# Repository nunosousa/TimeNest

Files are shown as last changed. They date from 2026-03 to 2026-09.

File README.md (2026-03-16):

# TimeNest

<p align="center">
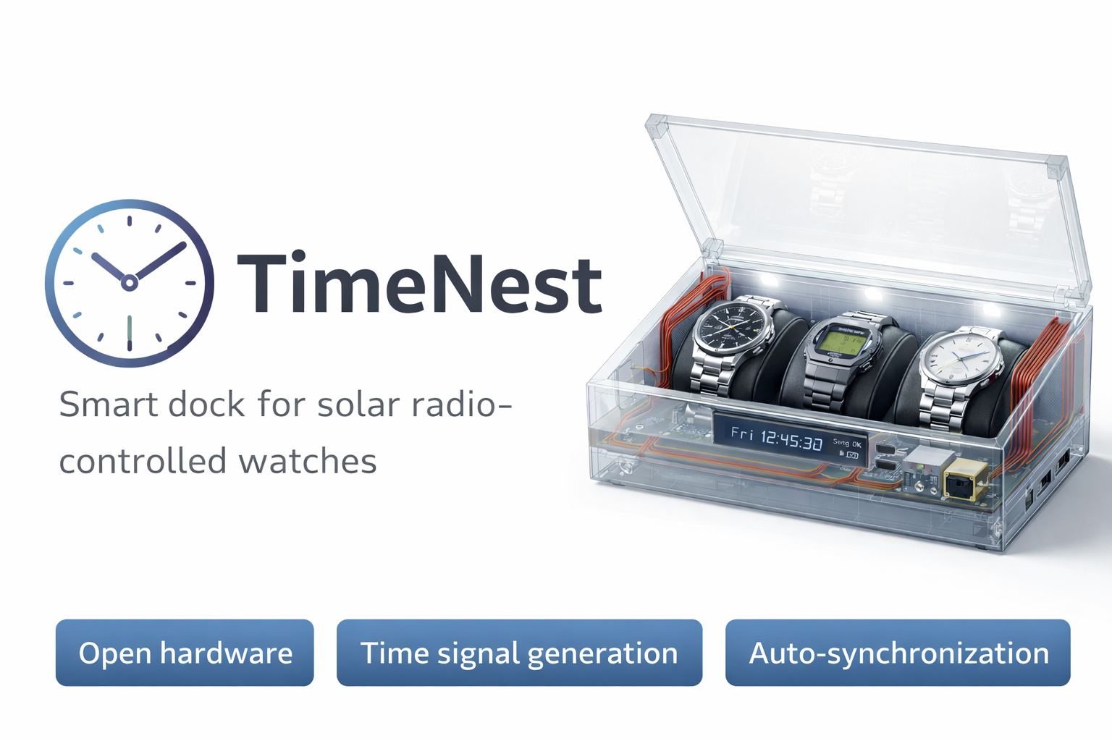
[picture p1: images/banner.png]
TimeNest banner
  
</p>

**TimeNest** is an open hardware dock that stores and automatically synchronizes radio-controlled solar watches using a locally generated low-frequency time signal.

The device acts as a **watch storage case, time synchronization beacon, and solar charging station**.

Watches placed inside the dock can synchronize reliably even in locations with poor LF radio reception.

---

## Overview

Many radio-controlled watches rely on long-wave radio signals (such as DCF77) to synchronize their time automatically.  
However, indoor reception can often be unreliable due to building structures and interference.

**TimeNest** solves this by generating a **local time signal** synchronized via the internet (SNTP) and transmitting it inside the watch case.

The result is a simple workflow:

1. Place watches inside the case  
2. Close the lid  
3. Watches synchronize automatically

---

## Features

### Radio Time Beacon

- Local generation of radio time signals (DCF77 initially)
- Near-field magnetic antenna
- Adjustable transmission power
- Designed to operate only within the watch case

### Watch Dock

- Storage for multiple watches
- Transparent lid
- Embedded antenna coils inside the case walls
- Elegant desk-friendly design

### Solar Charging

- LED illumination for solar watches
- Configurable brightness
- Optional ambient light sensing
- Illumination scheduling (e.g. daylight simulation)

### Connectivity

- Ethernet time synchronization (SNTP)
- Web configuration interface
- USB serial console for debugging and configuration

### Display

- Current time
- Synchronization status
- Transmission status
- System diagnostics

---

## System Architecture

- RP2040
    - Ethernet MAC + PHY (SPI)
    - lwIP + FreeRTOS
    - SNTP client
    - HTTP configuration server
    - USB serial console
    - DCF77 signal generator
    - external DAC
    - antenna driver
    - LED lighting control
    - display driver

## Platform Choice: RP2040

TimeNest is built around the **RP2040 microcontroller** rather than a microcontroller with an integrated Ethernet MAC. This decision was made deliberately based on several engineering and practical considerations.

### Availability and Supply Stability

One of the primary design goals for TimeNest is long-term reproducibility. During the global semiconductor shortages of 2020–2023 many commonly used MCUs became difficult to source, often with lead times exceeding a year.

The RP2040 demonstrated unusually strong supply stability during that period and remains widely available through multiple distributors. This makes it a reliable choice for a project intended to be reproducible by others in the future.

### Cost Efficiency

The RP2040 is inexpensive compared to many microcontrollers with integrated Ethernet peripherals. Even when combined with an external SPI Ethernet controller, the overall bill of materials remains competitive while retaining design flexibility.

### Strong Ecosystem

The RP2040 has a large and active ecosystem:

- extensive documentation
- a widely used SDK
- strong hobbyist and open hardware community
- support for multiple development environments

This lowers the barrier for contributors and improves long-term maintainability of the project.

### Deterministic Peripherals (PIO)

The RP2040 includes **Programmable I/O (PIO)** peripherals which allow precise timing control independent of the CPU.

This capability is particularly valuable for TimeNest because the device must generate a very stable **low-frequency radio time signal**. Using PIO allows deterministic waveform generation while the main CPU handles networking and other tasks.

### Dual-Core Architecture

The RP2040 provides two CPU cores, which allows the firmware to separate responsibilities:

- one core can handle networking, configuration, and user interface
- the other can manage the timing-critical signal generation tasks

This separation simplifies the firmware architecture and reduces the risk that networking activity interferes with signal timing.

### Flexible Networking Architecture

Although the RP2040 does not include an Ethernet MAC, TimeNest uses an external Ethernet controller connected via SPI.

This approach has several advantages:

- the networking stack remains fully software controlled
- updates and security fixes can be applied through the firmware
- the design avoids reliance on proprietary TCP/IP offload hardware

The project uses a standard embedded TCP/IP stack, making the networking layer maintainable and transparent.

### Simplicity and Accessibility

Another design goal for TimeNest is accessibility for hobbyists and hardware enthusiasts. The RP2040 is widely known and easy to work with, which makes the project easier to reproduce, understand, and modify.

---

### Summary

The RP2040 was chosen because it offers an excellent balance of:

- availability
- cost
- deterministic timing features
- strong community support
- long-term maintainability

While other microcontrollers could provide integrated Ethernet, the RP2040 provides the flexibility and ecosystem that best fit the goals of the TimeNest project.

---

## Why Generate a Local Radio Time Signal?

Many modern watches automatically synchronize their time using long-wave radio transmitters such as **DCF77 (Europe)**, **MSF (UK)**, **WWVB (USA)**, or **JJY (Japan)**.

However, reliable reception of these signals can be difficult indoors due to several factors:

- reinforced concrete buildings
- electrical interference
- distance from transmitters
- geographic coverage limitations

Even within nominal coverage areas, radio-controlled watches often fail to synchronize when placed inside buildings or urban environments.

TimeNest addresses this problem by generating a **local replica of the time signal** synchronized via the internet. The device obtains accurate time using SNTP and then reproduces the radio time signal within the enclosure.

This approach provides several advantages:

- reliable synchronization independent of outdoor reception
- consistent behavior regardless of building environment
- the ability to synchronize multiple watches simultaneously
- predictable synchronization during nightly update windows

By recreating the signal locally, TimeNest effectively acts as a **small personal time beacon** dedicated to the watches placed inside the dock.

---

## Near-Field Magnetic Transmission

TimeNest does not attempt to replicate a full long-range radio transmitter. Instead, it uses **near-field magnetic coupling** to deliver the time signal inside the watch enclosure.

Radio-controlled watches typically contain a **ferrite rod antenna** designed to detect the magnetic field component of long-wave signals. These antennas are very sensitive to nearby magnetic fields even when the radiated electric field is extremely small.

TimeNest takes advantage of this by generating a controlled magnetic field inside the watch case using tuned coils embedded in the enclosure walls.

This design has several benefits:

- extremely low transmission power
- minimal electromagnetic emissions outside the enclosure
- improved reliability for watches placed inside the case
- simplified antenna design

Because the signal only needs to be received within the watch compartment, the system operates entirely in the **near field** rather than attempting long-distance radio transmission.

The result is a compact and efficient system that reliably couples the time signal directly into the watch antennas while keeping the signal confined to the enclosure.

---

## Why Ethernet Instead of Wi-Fi?

TimeNest uses **wired Ethernet** as its network interface instead of Wi-Fi. This was a deliberate design choice based on simplicity, reliability, and the nature of the project.

### Simplicity of Implementation

The primary reason for choosing Ethernet is **system simplicity**.

Supporting Wi-Fi significantly increases firmware and system complexity. A Wi-Fi device must typically implement:

- network discovery and provisioning
- credential storage and management
- connection retry logic
- captive portal or mobile setup workflows
- security updates and maintenance

In contrast, Ethernet provides a **plug-and-play networking experience**:

1. Connect the cable.
2. Obtain an IP address via DHCP.
3. Start synchronizing time.

For a spare-time project, reducing firmware complexity greatly improves development speed and long-term maintainability.

### Reliability

Ethernet also offers **predictable and stable connectivity**. Wired networking avoids common Wi-Fi issues such as:

- RF interference
- signal dropouts
- congestion in the 2.4 GHz band
- router compatibility problems

For a device whose role is to **continuously obtain accurate time from the network**, a stable connection is desirable.

### Timing Considerations

TimeNest synchronizes time over the internet (e.g., via NTP) and generates a **DCF77-compatible time signal**. The required timing accuracy for this application is on the order of **tens of milliseconds**, which both Ethernet and Wi-Fi can easily support.

Therefore, Ethernet was **not chosen for better timing precision**—Wi-Fi would also be sufficient. The decision is instead driven by **simplicity and robustness**.

### Hardware and Firmware Complexity

Adding Wi-Fi would introduce additional hardware and software considerations:

- integration of a radio module
- antenna placement and RF layout constraints
- increased firmware stack complexity
- additional power consumption
- more complex debugging

Using Ethernet allows the device to remain **architecturally simple and deterministic**, which aligns well with the engineering goals of this project.

### Regulatory Considerations

Ethernet-only devices are treated as **unintentional radiators** from an electromagnetic compatibility (EMC) perspective. Adding Wi-Fi would turn the device into an **intentional RF transmitter**, bringing additional regulatory requirements under radio equipment directives.

While this is mainly relevant if the project were ever commercialized, avoiding an integrated radio simplifies the compliance landscape.

### Product Positioning

Many professional time distribution devices—such as **NTP servers and timing appliances**—use wired networking for the same reasons: reliability, determinism, and simplicity.

TimeNest follows this philosophy by favoring a **stable wired network interface** rather than a wireless one.

---

In short, Ethernet was selected because it provides the **simplest, most reliable, and most maintainable networking solution** for the goals of this project.

---

## Design Principles

TimeNest is designed as an open hardware project with an emphasis on simplicity, reproducibility, and responsible radio use. The following principles guide the design decisions throughout the project.

### Reproducibility

A core goal of TimeNest is that the device can be built and modified by others. Component choices and system architecture are selected with long-term availability in mind, and all design files are published in the repository.

The project includes:

- PCB design files
- firmware source code
- enclosure CAD models
- documentation describing design decisions

This allows others to reproduce, study, and extend the device.

### Modularity

TimeNest separates major system responsibilities into independent modules:

- RF signal generation
- networking and time synchronization
- user interface
- enclosure and antenna system

This modular structure simplifies development and makes the system easier to maintain or extend.

### Deterministic Timing

Generating a reliable radio time signal requires stable and predictable timing. The system architecture therefore prioritizes deterministic signal generation and isolates time-critical tasks from networking and user interface functionality.

This ensures that background tasks such as networking or configuration do not interfere with signal generation.

### Minimal RF Emissions

TimeNest is designed to operate entirely within the watch enclosure using near-field magnetic coupling rather than long-range radio transmission.

This approach:

- minimizes radiated emissions
- reduces interference with other devices
- keeps the system focused on synchronizing watches inside the dock

### Transparency

Design decisions are documented whenever possible so that the reasoning behind the system architecture is clear. Open documentation helps contributors understand the project and provides useful reference material for similar designs.

### Practical Simplicity

Where possible, the design favors simple and robust solutions over unnecessary complexity. The goal is a device that is reliable, understandable, and easy to reproduce rather than one that maximizes feature count.

---

## How It Works

TimeNest synchronizes radio-controlled watches by recreating a standard long-wave time signal inside the watch enclosure. The device obtains accurate time from the internet and converts it into a locally generated radio time signal that watches can receive.

The signal path can be summarized as follows:

<p align="center">
  
</p>

### Time Synchronization

TimeNest retrieves accurate time using **SNTP (Simple Network Time Protocol)** over Ethernet.  
The device periodically synchronizes with an NTP server and maintains a local system clock.

### Time Signal Encoding

Once the correct time is known, the firmware constructs the **DCF77 time frame**, which encodes:

- current minute
- hour
- date
- day of week
- daylight saving time information
- parity bits

DCF77 transmits one bit per second using amplitude modulation of a 77.5 kHz carrier.

### Carrier Generation

The RF carrier is generated using a **Direct Digital Synthesis (DDS)** approach implemented on the RP2040.  
The DDS produces a stable 77.5 kHz waveform that serves as the carrier for the time signal.

### Modulation

The DCF77 signal encodes bits using brief reductions in carrier amplitude:

- **100 ms reduction** → logical 0  
- **200 ms reduction** → logical 1  

The firmware controls this modulation pattern according to the generated time frame.

### Analog Signal Output

The synthesized waveform is converted to an analog signal using a **digital-to-analog converter (DAC)** and then amplified by a small RF driver stage.

### Magnetic Field Generation

The amplified signal drives **resonant antenna coils embedded in the enclosure walls**. These coils generate a low-frequency magnetic field inside the watch compartment.

Because radio-controlled watches use **ferrite rod antennas**, they can detect this magnetic field even though the transmission power is extremely small.

### Watch Synchronization

Watches placed inside the dock receive the locally generated signal just as they would receive the original DCF77 transmission. During their normal nightly synchronization window, the watches decode the signal and update their internal clocks.

By generating the signal locally, TimeNest ensures reliable synchronization even in environments where the original long-wave broadcast cannot be received.

---

## Hardware

Main components include:

- RP2040 microcontroller
- SPI Ethernet controller
- external DAC for signal generation
- resonant LF antenna coils
- LED lighting system
- small display
- optional RTC

Hardware design files can be found in:

hardware/pcb

---

## Antenna

TimeNest uses **near-field magnetic transmission**.

Two coils embedded in the case walls generate a uniform magnetic field inside the watch compartment, allowing reliable synchronization for all watches inside the box.

---

## Enclosure

The enclosure is a **3D-printed watch case** designed to hold multiple watches.

Features include:

- transparent lid
- integrated antenna coils
- solar charging LEDs
- front status display
- rear connectors (Ethernet, USB, power)

CAD files are located in:

enclosure/cad

---

## Repository Structure

- TimeNest
    - firmware/ RP2040 firmware
    - hardware/ schematics and PCB layout
    - enclosure/ CAD models and STL files
    - docs/ design notes and documentation
    - images/ renders and photos

---

## Roadmap

| Feature | Status |
|---|---|
| Project concept | ✅ done |
| System architecture | 🔄 in progress |
| RP2040 platform selection | 🔄 in progress |
| DCF77 signal generator | ⏳ planned |
| DAC output stage | ⏳ planned |
| Antenna design | ⏳ planned |
| Ethernet networking | ⏳ planned |
| SNTP time synchronization | ⏳ planned |
| Web configuration interface | ⏳ planned |
| USB debug interface | ⏳ planned |
| Solar charging LEDs | ⏳ planned |
| Enclosure CAD design | ⏳ planned |
| Multi-protocol support (WWVB / MSF / JJY) | 💡 future idea |

Legend:

⏳ planned

🔄 in progress

✅ done

💡 future idea

---

## Development Log

- 2026-03 — project started
- architecture defined
- antenna concept explored
- enclosure concept designed

More updates will be added as development progresses.

---

## Getting Started

Documentation and assembly instructions will be added as the hardware and firmware mature.

---

## Contributing

Contributions, ideas, and feedback are welcome.

If you are interested in:

- RF design
- embedded firmware
- mechanical design
- watch technology

feel free to open an issue or start a discussion.

---

## Project Status

TimeNest is currently in **early development**.

## Acknowledgements

Some parts of the project documentation and early concept brainstorming were assisted by AI tools.  
All hardware, firmware, and mechanical design decisions are reviewed and implemented by the project author.

## License

TimeNest is an open hardware project.

Different parts of the project are licensed under different licenses:

| Component | License |
|---|---|
Firmware | MIT License |
Hardware (schematics, PCB) | CERN-OHL-S v2 |
Enclosure CAD | CERN-OHL-S v2 |
Documentation and images | CC BY 4.0 |

See the `LICENSES` folder for full license texts.

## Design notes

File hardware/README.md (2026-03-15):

# Hardware

This directory contains the electronic design files for TimeNest.

## Contents

- schematics
- PCB layout
- component libraries
- manufacturing files

The main PCB includes:

- RP2040 microcontroller
- Ethernet MAC/PHY
- DAC for signal generation
- antenna driver
- LED drivers
- power supply circuitry

## Tools

The PCB is designed using KiCad.

## Status

Hardware design is currently in early development.

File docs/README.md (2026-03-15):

# Documentation

This directory contains technical documentation related to the TimeNest project.

Topics include:

- antenna design
- RF signal generation
- system architecture
- testing procedures
- assembly instructions

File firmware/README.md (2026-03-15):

# Firmware

This directory contains the firmware for the TimeNest device.

The firmware runs on the RP2040 microcontroller and is responsible for:

- generating the DCF77 signal
- controlling the antenna driver
- managing LED solar charging
- providing USB console access
- handling Ethernet networking and SNTP synchronization
- driving the display

## Structure

rp2040/ main firmware project

drivers/ hardware drivers

protocols/ time signal generation

ui/ display and console interface

## Build System

Firmware is built using the RP2040 SDK.

Further build instructions will be added as development progresses.

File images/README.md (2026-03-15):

# Images

This directory contains project images used in documentation.

Examples:

- device renders
- architecture diagrams
- PCB previews
- antenna illustrations

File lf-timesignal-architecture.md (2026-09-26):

# LF Time-Signal Generator — Architecture Sketch
## (single-standard per build, five variants from one design)

Target: a near-field transmitter that emits **one** LF time signal — DCF77,
WWVB, MSF, JJY (40/60) or BPC — to synchronise consumer radio-controlled
watches and clocks, with full fidelity including DCF77 phase modulation and
WWVB BPSK.

**The standard is fixed at build time**, not runtime-selectable: one PCB design
with a per-variant BOM (tank capacitor, PLL constants) and firmware build flag.
This constraint is exploited throughout — in §2, §3 and §6 it removes problems
rather than adding them.

**Companion documents:**
- `lf-timesignal-requirements.md` — formal design requirements
- `lf-timesignal-hardware.md` — schematic blocks, part selection, PCB design

---

## 1. Top-level block diagram

```
 ┌────────────┐  UART+PPS   ┌──────────────────────────────────────┐
 │ GNSS module├────────────►│              RP2350                  │
 └────────────┘             │                                      │
 ┌────────────┐    I2C      │  core0: timebase, GNSS, UI, config    │
 │ RTC+cell   ├────────────►│  core1: NCO sample synthesis          │
 └────────────┘             │  PIO0:  R-2R sample clock (DMA fed)   │
 ┌────────────┐             │  PIO1:  PPS capture / spare           │
 │ TCXO       ├──► XIN      └───────────────┬──────────────────────┘
 └────────────┘                             │ 10-bit parallel
                                            ▼
                              ┌──────────────────────────┐
                              │ R-2R ladder (10-bit)     │
                              └────────────┬─────────────┘
                                           ▼
                              ┌──────────────────────────┐
                              │ Reconstruction LPF ~120k │
                              └────────────┬─────────────┘
                                           ▼
                              ┌──────────────────────────┐
                              │ Linear driver (op-amp)   │
                              └────────────┬─────────────┘
                                           ▼
                              ┌──────────────────────────┐
                              │ Untuned / damped loop    │
                              └──────────────────────────┘
```

Everything downstream of the R-2R is **linear** — no switching stages — because
the signal now carries simultaneous amplitude *and* phase information.

---

## 2. Clocking and the sample rate — **coherent sampling, per variant**

Because each unit is built for **one** standard (see §2a), the system clock and
sample rate are chosen per variant so that:

```
Fs = N × f_carrier     (N = integer samples per carrier cycle)
sysclk = M × Fs        (M = integer PIO divider)
Fs = integer samples per second
```

This is *coherent sampling*, and it is only possible in a single-standard build.
It is a large simplification — see §3 for why.

| Variant | sysclk | PLL (refdiv/fbdiv/VCO/p1/p2) | Fs | N (samp/cycle) | PIO div | cycles/sample |
|---|---|---|---|---|---|---|
| DCF77 77.5k | 116.25 MHz | 2 / 155 / 930 MHz / 2 / 4 | 1.550 MS/s | 20 | 75 | 75 |
| WWVB 60k | 102.00 MHz | 1 / 68 / 816 MHz / 2 / 4 | 1.200 MS/s | 20 | 85 | 85 |
| MSF 60k | 102.00 MHz | 1 / 68 / 816 MHz / 2 / 4 | 1.200 MS/s | 20 | 85 | 85 |
| JJY 40k | 100.00 MHz | 1 / 75 / 900 MHz / 3 / 3 | 0.800 MS/s | 20 | 125 | 125 |
| BPC 68.5k | 102.75 MHz | 2 / 137 / 822 MHz / 2 / 4 | 1.370 MS/s | 20 | 75 | 75 |

All verified against RP2350 PLL constraints (VCO 750–1600 MHz, fbdiv 16–320,
postdiv 1–7). **N = 20 for every variant**, so the sine LUT, the DDS inner loop
and the DMA block sizing are identical across the whole family — only three
constants change.

Note that **BPC's awkward prime 137 is no longer a problem**: it is absorbed
directly into the PLL feedback divider (refdiv 2, fbdiv 137 → 822 MHz VCO). The
factor that made a runtime-switchable design impossible is free in a
per-variant one.

Sysclk also drops from 150 MHz to ~100–116 MHz, which reduces power and
lengthens the per-sample CPU budget.

---

## 2a. Product variants

One PCB, one firmware tree, per-variant BOM and build flags. Two complexity
tiers fall out of *which standards carry phase modulation*:

| Tier | Standards | Modulation | Signal chain |
|---|---|---|---|
| **Full** | DCF77, WWVB | AM **+ phase** (PRBS / BPSK) | NCO → R-2R → LPF → linear driver |
| **Simple** | MSF, JJY, BPC | AM / OOK only | PIO square wave → keying → tank |

The Simple tier needs no DAC, no linear amplifier and no reconstruction filter —
a PIO square wave into a tuned tank with switched drive is sufficient, because
there is no phase information to preserve. That is a materially cheaper kit.

**Recommendation: lay out one PCB that supports both**, with the R-2R ladder,
filter and linear driver as do-not-populate options on Simple-tier builds. Two
separate PCB designs would double layout, inventory and test-fixture work to
save a few euro of parts.

Per-variant differences are then: crystal/PLL constants, tank capacitor,
firmware build flag, silkscreen, and test limits.

---

## 3. The NCO — now *coherent*, which removes two problems

With Fs locked to an integer multiple of the carrier (N = 20), the NCO stops
being a general-purpose DDS and becomes something much simpler and more exact.

**The phase accumulator no longer accumulates error.** With N = 20 samples per
cycle, the carrier phase advances by exactly 1/20 turn per sample. A 20-entry
sine table *is* the carrier. There is no phase truncation, no fractional
residual, and therefore **no DDS phase-truncation spurs** — which were the main
spectral risk of the original design.

Keep a 32-bit accumulator anyway (it costs nothing and preserves the ability to
trim frequency for calibration), but the steady-state increment is now the exact
value `2^32 / 20`, and the arithmetic closes perfectly every 20 samples.

Modulation is unchanged and still trivial:
- **PM/BPSK** = add to `phase_offset` (±15.6° DCF77, 180° WWVB)
- **AM** = scale `amplitude` (15% DCF77, −17 dB ≈ 14.1% WWVB, 0% MSF, ~10% JJY)

Because a full carrier cycle is exactly 20 samples, a 180° BPSK reversal is
exactly a 10-sample index offset, and DCF77's ±15.6° needs interpolation or a
slightly larger LUT (a 256-entry table indexed by the accumulator's high bits
handles both cleanly).

### The DCF77 chip-alignment problem disappears

Previously flagged as a trap: at 2 MS/s a DCF77 PM chip was 3096.774 samples —
not an integer — so a sample counter would drift against the chip clock.

With coherent sampling this vanishes:

```
chip = 120 carrier cycles × 20 samples/cycle = 2400 samples, exactly
```

No overflow-counting workaround, no drift, no self-aligning trickery. A plain
sample counter is now exact. Similarly one second = 1 550 000 samples exactly,
so second boundaries and chip boundaries stay locked forever.

This is the single strongest argument for the per-variant approach.

### DCF77 PM timing, in samples (verified self-consistent)

| Event | Time | Samples @ 1.55 MS/s |
|---|---|---|
| 1 carrier cycle | 12.9 µs | 20 |
| 1 second | 1 s | 1 550 000 |
| 1 PM chip (120 cycles) | 1.5484 ms | 2 400 |
| PM start | +200 ms | 310 000 |
| PM duration (512 chips) | 792.77 ms | 1 228 800 |
| PM end | +992.77 ms | 1 538 800 |
| Guard before next second | 7.23 ms | 11 200 |
| AM drop, bit 0 | 100 ms | 155 000 |
| AM drop, bit 1 | 200 ms | 310 000 |
| AM ramp | 1.0 ms | 1 550 |

512 chips at 645.833 Hz = 792.77 ms, starting at +200 ms, ending at +992.77 ms —
inside the second with 7.23 ms to spare. The +200 ms start is exactly what keeps
PM clear of the longest AM drop, satisfying the "no phase modulation during the
amplitude drop" constraint structurally rather than by special-casing.

Every quantity above is an exact integer number of samples.

---

## 3a. Epoch discipline without touching the carrier

A subtle but important consequence of coherent sampling.

The carrier NCO **free-runs and is never steered**. Because f_c = F_s/20 is
structural, a reference-oscillator error scales the carrier, the chip rate and
the second length *together* — so a DCF77 chip stays exactly 120 carrier cycles
no matter how far off the crystal is.

Timing is therefore disciplined in the **event scheduler**, not the oscillator:
maintain a fractional samples-per-second accumulator (nominally 1 550 000) and
steer it against GNSS PPS. Because the carrier accumulator is untouched, this
introduces **no carrier phase glitch** — which would otherwise corrupt PM and
BPSK, and would be very hard to diagnose.

Consequences:
- Carrier accuracy requirement is loose (±10 ppm), so the reference is chosen
  for **holdover stability**, not absolute accuracy.
- Steering resolution is unlimited (fixed-point remainder), not quantised to
  whole samples.
- Never implement discipline by inserting/dropping samples: at 20 samples per
  cycle, one sample is an 18° phase step.

---

## 4. Software layering

Three layers with narrow interfaces. The whole point is that adding a sixth
standard should touch only layer 2.

### Layer 1 — Timebase service
Produces a sample-accurate UTC: `(utc_seconds, sample_within_second)`.

- GNSS PPS captured against the free-running sample counter.
- Steer/align the second boundary; measure TCXO error over long intervals and
  store the learned ppm correction in flash for holdover.
- Leap-second state (current + pending) taken from the GNSS navigation message.
- RTC (battery-backed) provides time across power cycles.

### Layer 2 — Standard / protocol layer
`utc → local time for that standard → frame bits → symbol schedule`

- DST/offset rule engine (§5).
- One frame encoder per standard, each a pure function of civil time → bits.
- Emits a **symbol schedule**: a list of
  `{ sample_offset, amplitude_q15, phase_offset_q32, ramp_samples }` events for
  the coming second, plus an optional PRBS generator hook for DCF77 PM.

### Layer 3 — Modulator
Consumes the symbol schedule, runs the NCO, fills double-buffered DMA blocks
(e.g. 512 samples) on core1. Knows nothing about time or standards.

This split keeps the twice-a-year DST bugs and the real-time DSP in completely
separate, separately-testable code.

---

## 5. Time, date and DST — no network needed

GNSS supplies UTC, date and leap-second data (including *pending* leap seconds,
which is better than NTP's last-day-only leap indicator).

**Holdover is the binding constraint, not acquisition.** Measured budget:

| Reference | Residual | Drift | Reaches 100 ms in |
|---|---|---|---|
| Plain XTAL, uncorrected | 30 ppm | 2.6 s/day | 1 hour |
| Plain XTAL, ppm learned | ~3 ppm | 259 ms/day | 9 hours |
| TCXO 2 ppm | 2 ppm | 173 ms/day | 14 hours |
| **TCXO 0.5 ppm** | 0.5 ppm | 43 ms/day | **2.3 days** |

Even a good TCXO holds ±100 ms for only about two days, so **"get one fix at
setup and run forever" is not viable**. The design answer is duty-cycled GNSS:
re-acquire hourly (cheap in power, ~seconds of tracking), and treat true
holdover as a degraded mode specified at ±500 ms over 7 days — which 0.5 ppm
does meet.

This also means the GNSS antenna should be external and user-placeable, not a
patch buried in the enclosure.

GNSS does not supply timezone or DST rules — but none of these standards need a
tzdata database, because each broadcasts exactly one zone under one fixed
algorithmic rule:

| Standard | Zone | DST rule |
|---|---|---|
| DCF77 | CET/CEST | EU: last Sun Mar 01:00 UTC → summer; last Sun Oct 01:00 UTC → winter |
| MSF | UTC/BST | Same instants as the EU rule |
| WWVB | UTC + DST status bits | US: 2nd Sun Mar, 1st Sun Nov |
| JJY | JST (UTC+9) | None |
| BPC | UTC+8 | None |

~30 lines of "Nth/last Sunday of month" arithmetic. **Store the rule parameters
in flash, not hardcoded**, so a future EU decision to abolish DST is a config
change rather than a firmware respin.

Announce bits are computed from the same rules: DCF77 A1 (bit 16) during the
hour before a change, A2 (bit 19) for leap seconds, and WWVB's DST status bits.
*Pin the exact announce timing against the PTB and NIST specs — these are the
classic "works all year, fails twice a year" defects.*

---

## 6. Output stage — now tuned, but *not* high-Q

Per-variant tuning removes the objections that forced an untuned loop in the
runtime-switchable design: a single fixed resonant frequency means **no switched
capacitor bank and no per-band phase calibration**. So yes — resonate.

The question becomes *how high a Q*, and there are two independent ceilings.

### Ceiling 1 — modulation bandwidth

`BW = f0 / Q`, ring-down `τ = Q / (π·f0)`.

| Variant | Constraint | Required BW | Q ceiling |
|---|---|---|---|
| DCF77 | PM chips at 645.83 Hz | ≳ 3 kHz | **~25** |
| WWVB | BPSK reversal, 1 baud | transient ≪ 1 s | ~100 |
| MSF | OOK, 100 ms off | ring-down ≪ 100 ms | ~100 |
| JJY / BPC | AM, ≥ 200 ms | loose | ~100 |

Only DCF77 is genuinely tight. At Q = 25 its ring-down is 103 µs — negligible
against a 100 ms AM step, while still passing the phase chips.

### Ceiling 2 — manufacturability (this is the binding one for a kit)

At Q = 50 and 77.5 kHz the passband is 1550 Hz. A ±5% capacitor shifts
resonance by ~2.5%, i.e. ~1900 Hz — **further than the bandwidth is wide**. The
unit would ship detuned off its own peak.

High Q therefore forces either 1% C0G capacitors *and* a per-unit tuning step,
or a trimmer the customer must adjust with test gear they don't own. For a kit,
that is a support disaster.

**Q ≈ 20–25 is the sweet spot, and it is the same answer for every variant.**
It satisfies DCF77's phase modulation, tolerates ±2–3% component spread with no
per-unit tuning, and keeps one Q target across the whole product family.

Use **C0G/NP0 capacitors** regardless — X7R's temperature and DC-bias drift
would detune the tank across the operating range.

### Don't over-value the range gain

Field strength in a series-resonant loop scales with Q, but near-field coupling
falls as 1/r³. So going Q = 25 → 100 (4× current) buys only ∛4 ≈ **1.6× range**.
Paying for per-unit tuning to gain 60% more distance on a device meant to work
at a few centimetres is a bad trade.

### Worked example (DCF77)

L = 1 mH at 77.5 kHz → ωL = 487 Ω. C = 4.22 nF (C0G).
For Q = 25, total series R = 19.5 Ω. Ring-down τ = 103 µs. BW = 3.1 kHz.

### Drive requirement — no power amplifier needed

Computed field strength settles this. A 100-turn, 5 cm-radius loop at **10 mA
peak** sits roughly **65 dB under FCC §15.209** and **70 dB under EN-300-330**-
style limits, while still delivering a very strong near-field at watch distance.

| Coil current | Drive voltage | Power | Voltage across L |
|---|---|---|---|
| 10 mA pk | 0.19 V pk | 1.0 mW | 4.9 V pk |
| 30 mA pk | 0.58 V pk | 8.8 mW | 14.6 V pk |
| 50 mA pk | 0.97 V pk | 24.3 mW | 24.3 V pk |

The "linear amplifier" in the original block diagram is therefore just an
op-amp: 1 mW, 0.19 V peak, and a slew-rate requirement of 0.49 V/µs. Select for
distortion, not for power.

⚠️ **The voltage across the inductor is Q× the drive** — 24 V peak at 50 mA on a
5 V system. Rate the tank capacitor ≥50 V. This is the standard resonant-circuit
trap and the one place in this design where a 5 V assumption will destroy parts.

### DAC and filter (Full tier only)

10-bit R-2R, PIO+DMA driven, 0.1% resistors (1% parts give ~7 effective bits;
WWVB's −17 dB level wants ~1% amplitude accuracy). Reconstruction LPF at
~120 kHz. Phase resolution lives in the NCO, not the DAC — DAC bits bound only
amplitude accuracy and the spurious floor.

Simple-tier variants (MSF/JJY/BPC) omit all of this: PIO square wave → keyed
drive → tank. The tank's own selectivity suppresses the square wave's harmonics.

---

## 7. Pin budget (RP2350)

| Function | Pins |
|---|---|
| R-2R ladder | 10 |
| GNSS UART (TX/RX) | 2 |
| GNSS PPS | 1 |
| GNSS enable | 1 |
| I2C (RTC + OLED) | 2 |
| Amplifier mute/enable | 1 |
| UI (encoder + button) | 3 |
| Status LED | 1 |
| Optional band-select switches | 3 |
| **Total** | **~21–24** |

Fits the 30-GPIO QFN-60 package with margin. Simple-tier variants free the 10
R-2R pins, leaving room for a cheaper/smaller package if a cost-reduced SKU is
ever wanted.

---

## 8. Configuration and UX

The standard is **fixed at build time** (BOM + firmware flag), so there is no
runtime standard selector. What remains configurable in flash:

- TX power trim, DST rule parameters, learned TCXO ppm, transmit window.
- No OLED/encoder needed for standard selection — a status LED plus USB-C serial
  config is sufficient, which cuts BOM and enclosure cost.
- **Transmit window scheduler**: most radio-controlled watches only attempt sync
  overnight (typically 02:00–04:00), so the device can idle most of the day.
  Cuts duty cycle, power and regulatory exposure — and is a genuine product
  feature ("only radiates 20 minutes a night").
- Provide a manual "sync now" button for watches that support forced receive;
  without it, development iterations take hours.
- **Have the firmware refuse to run if the build flag and a hardware strap
  disagree.** A DCF77 board flashed with WWVB firmware would transmit off-tune
  into a Q=25 tank and mostly just not work — an expensive support ticket.
  A single resistor strap per variant makes this self-detecting.

---

## 9. Test and validation strategy

- **A 192 kHz USB audio interface is your best analysis tool.** Nyquist is
  96 kHz, so all five carriers (40, 60, 68.5, 77.5 kHz) fit directly in the
  audio band. No SDR or upconverter needed — capture the loop with a pickup coil
  and decode/analyse in software.
- Commercial DCF77/WWVB/MSF receiver modules as golden-reference decoders.
- A second RP2350 running a decoder for loopback regression tests.
- **Golden-vector unit tests**: known timestamp → expected bit pattern, per
  standard, checked bit-for-bit against published examples.
- **Sweep the DST engine across ~20 years** of transitions in unit tests,
  including the leap-second and announce-bit edges.
- **Per-variant production test**: sweep the tank and confirm resonance lands
  within ±1% of target. Cheap to automate with the same audio interface, and it
  is the one build defect (wrong/out-of-tolerance capacitor) most likely to
  escape a kit builder.

---

## 10. Risks

| Risk | Severity | Mitigation |
|---|---|---|
| Regulatory compliance **per variant per region** | **High** | Each variant is a separate frequency in a separate jurisdiction — FCC (WWVB), CE/UKCA (DCF77/MSF), MIC (JJY, notoriously strict). Cost multiplies per variant, so launch **one** variant first and treat others as gated business decisions, not engineering tasks |
| GNSS never gets a fix indoors | High | RTC holdover + learned TCXO correction; only needs one fix at setup; USB time-set fallback |
| Kit builder mis-tunes or mis-stuffs the tank | Medium | Q≈25 tolerates ±2–3% spread; ship pre-matched L/C pair; hardware strap + firmware self-check |
| DCF77 PRBS spec details (sequence, start offset within the second) | Medium | Obtain PTB specification before committing to layer-2 design |
| WWVB BPSK +0.1 s offset implemented wrong | Medium | Breaks BPSK receivers while AM ones still work — looks intermittent. Cover with golden vectors |
| R-2R amplitude accuracy (Full tier only) | Low | 0.1% resistors, or monolithic DAC in production |
| GPS week rollover | Low | Current module firmware; handle epoch explicitly |
| BPC spec availability (Chinese-language sources) | Low | Defer to last; lowest commercial value |

Note that selling a **kit** rather than a finished product does not reliably
reduce regulatory obligation — do not assume it does without advice.

---

## 11. Phased roadmap

Build **one variant end-to-end** before generalising. DCF77 first: it is your
own use case and it is the hardest (phase modulation + tightest Q ceiling), so
it validates every constraint the other variants will face.

| Phase | Goal | Proves |
|---|---|---|
| P0 | DCF77 AM only, square wave into a coil, time hardcoded | A watch actually syncs — de-risks the whole product in a weekend |
| P1 | NCO + R-2R + LPF + linear driver + Q≈25 tank, DCF77 AM | Coherent-sampling signal chain and CPU budget |
| P2 | DCF77 phase modulation | Hardest DSP; validates the Q≈25 ceiling |
| P3 | GNSS + PPS discipline + RTC holdover + DST engine | Standalone operation — **first sellable product** |
| P4 | Second variant (WWVB or MSF) | Layer-2 abstraction and the per-variant BOM actually hold |
| P5 | Enclosure, config, per-region compliance | Sellable abroad |
| P6 | JJY, BPC | Completeness |

Compared with the runtime-switchable plan, GNSS/DST moves **earlier** (it is
needed for a shippable single-standard unit) and multi-standard work moves
**later** (it is now a business decision gated on compliance cost, not a
prerequisite).

Do P0 first and separately. It is a few hours of work and it answers the only
question that really matters: do your watches sync to a locally generated
signal at all?

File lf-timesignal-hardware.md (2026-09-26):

# LF Time-Signal Generator — Hardware Design

Companion to `lf-timesignal-requirements.md` and `lf-timesignal-architecture.md`.
Requirement IDs (F-xx, P-xx, S-xx…) refer to the requirements document.

Values marked 🔶 need confirmation against a datasheet or a prototype
measurement before design freeze.

---

## 1. Block diagram (Full tier)

```
 USB-C 5V ──┬─ ESD ─┬─ LDO 3.3V DIGITAL ──── RP2350A, GNSS, RTC
            │       └─ LDO 3.0V ANALOG  ──┬─ R-2R buffers (reference!)
            │                              └─ op-amp rails
            └─ CC resistors

 TCXO 12 MHz 0.5ppm ──► XIN

 GNSS module ──UART──► RP2350      u.FL ──► active antenna
             ──PPS───►

 DS3231 + CR2032 ──I2C──► RP2350

 RP2350 GPIO0..9 ──► 74LVC244 ×2 ──► R-2R ladder ──► 3rd-order LPF
                       (clean 3.0V)                        │
                                                            ▼
                                            op-amp driver ──► Rsense ──► tank
                                                  │                      │
                                            ADC ◄─┴─ current sense       │
                                                                          ▼
                                                        external ferrite rod
```

Simple tier (MSF/JJY/BPC) depopulates the buffers, ladder, LPF and op-amp;
a PIO square wave drives the tank through a keyed gate stage.

---

## 2. Part selection

| Block | Part | Rationale / notes |
|---|---|---|
| MCU | **RP2350A**, QFN-60, 30 GPIO | Confirmed 30 GPIO — enough (§4). Dual M33, FPU, 12 PIO SM. 1.1 V core, 3.3 V IOVDD |
| Flash | W25Q32JV QSPI 4 MB | Ample; stores config + learned ppm |
| Reference | **12.000 MHz TCXO, ±0.5 ppm**, CMOS out | Driven by P-05 holdover. See §3 for XIN caveat 🔶 |
| GNSS | u-blox **MAX-M10S** (alt: NEO-M9N; budget: ATGM336H) | Low power, good PPS, duty-cycle friendly |
| GNSS antenna | Active patch, u.FL/SMA, 3.3 V bias | External so the user can place it near a window (P-05 mitigation) |
| RTC | **DS3231SN** + CR2032 | Integrated TCXO, ±2 ppm; backup only, not the transmit reference |
| DAC buffers | 2 × **74LVC244A** (or 1 × 74LVC16244) | Low, matched output impedance; isolates ladder from noisy IOVDD |
| Ladder | R = 10 kΩ / 2R = 20 kΩ, **0.1 % thin film** | See §5 for the tolerance analysis |
| Analog LDO | Low-noise 3.0 V (e.g. TPS7A20 / ADP7142 class) | This rail **is** the DAC reference — W-06 applies |
| Op-amp | Rail-to-rail, ≥ 50 mA out, ≥ 2 MHz GBW, low distortion | Requirement is tiny (§6) — many parts qualify 🔶 |
| Tank C | C0G/NP0, 2 %, ≥ 50 V | X7R drift would detune the tank |
| Antenna | Ferrite rod, ~1 mH, external lead | Orientation matters (E-06) |
| Connector | USB-C receptacle, 5 V only | |

---

## 3. Clock and timebase

**TCXO 12 MHz → RP2350 XIN.** PLL constants per variant (verified reachable:
VCO 750–1600 MHz, fbdiv 16–320, postdiv 1–7):

| Variant | refdiv | fbdiv | VCO | p1 | p2 | sysclk | PIO div | Fs |
|---|---|---|---|---|---|---|---|---|
| DCF77 | 2 | 155 | 930 MHz | 2 | 4 | 116.25 MHz | 75 | 1.550 MS/s |
| WWVB / MSF | 1 | 68 | 816 MHz | 2 | 4 | 102.00 MHz | 85 | 1.200 MS/s |
| BPC | 2 | 137 | 822 MHz | 2 | 4 | 102.75 MHz | 75 | 1.370 MS/s |
| JJY40 | 1 | 75 | 900 MHz | 3 | 3 | 100.00 MHz | 125 | 0.800 MS/s |

🔶 **Open item 5:** RP2350's XIN is a crystal-oscillator input; external-clock
drive level is constrained. Provide **both** a series-resistor/AC-coupled XIN
path *and* an alternate route to **GPIO20 (clk_gpin0)**, with the unused one
DNP. Decide after measuring on the first prototype. GPIO20 is reserved for this
reason.

### Why frequency accuracy is *not* the hard part

Carrier accuracy needs only ±10 ppm (S-01) — receiver front-ends are far
looser. What actually matters is **epoch** accuracy, and that is disciplined in
software: the scheduler keeps a fractional samples-per-second accumulator
(nominally 1 550 000) and steers it against GNSS PPS.

Crucially, the carrier NCO **free-runs** and is never steered. Because
f_c = F_s/20 structurally, a reference error scales carrier, chip rate and
second length together, so DCF77 chips remain exactly 120 carrier cycles
regardless of reference error. Steering the *scheduler* therefore introduces
**no carrier phase glitch** — which would otherwise corrupt PM/BPSK. This is
why the TCXO is a holdover part, not an accuracy part.

---

## 4. RP2350A pin allocation

| GPIO | Function | Notes |
|---|---|---|
| 0–9 | R-2R D0–D9 | **Must be contiguous** for PIO parallel OUT |
| 10 | Sample-clock test point | PIO side-set |
| 11 | Amplifier enable / mute | Safe state = muted |
| 12 | GNSS UART TX | |
| 13 | GNSS UART RX | |
| 14 | GNSS PPS in | PIO capture, ≤1 µs (P-04) |
| 15 | GNSS reset / enable | Duty-cycling |
| 16 | I2C0 SDA | DS3231 |
| 17 | I2C0 SCL | |
| 18 | RTC SQW / INT | 1 Hz cross-check |
| 19 | Variant strap 0 | |
| **20** | **Reserved: clk_gpin0** | Alternate TCXO route, DNP |
| 21 | Variant strap 1 | |
| 22 | Variant strap 2 | |
| 23 | Status LED | |
| 24 | User button ("sync now", F-09) | |
| 25 | PPS out test point | Bring-up and production test |
| 26 | ADC0 — coil current sense | Amplitude self-check, M-05 |
| 27 | ADC1 — 5 V rail monitor | |
| 28, 29 | ADC2/3 spare | |

30 GPIO, fully allocated with two spares. Simple-tier builds free GPIO0–9.

**Variant strap (I-08):** 3 GPIO, pull-up/down per build → 8 codes. Firmware
compares against its build flag and refuses to transmit on mismatch (F-11). A
DCF77 board running WWVB firmware would drive an off-tune Q≈25 tank and mostly
just not work — an expensive and confusing support case.

---

## 5. DAC: 10-bit R-2R

### Why buffered, not direct GPIO

Driving the ladder straight from GPIO makes **IOVDD the amplitude reference** —
and IOVDD carries the MCU's switching noise, which would appear as amplitude
modulation on the carrier. GPIO output impedance also varies with drive
strength and temperature.

So: 10 lines → 74LVC244 buffers → ladder, buffers powered from the clean 3.0 V
analog LDO. The buffers provide low, *matched* impedance and make the reference
a deliberate choice rather than an accident.

### Ladder value — computed trade-off

MSB-branch error from buffer output impedance R_o is R_o/(2R):

| R | R_o = 5 Ω | R_o = 10 Ω | R_o = 50 Ω | Thermal noise (200 kHz BW) |
|---|---|---|---|---|
| 2 kΩ | 1.3 LSB | 2.6 LSB | 12.8 LSB | 2.6 µVrms |
| 5 kΩ | 0.5 LSB | 1.0 LSB | 5.1 LSB | 4.1 µVrms |
| **10 kΩ** | **0.3 LSB** | **0.5 LSB** | 2.6 LSB | 5.8 µVrms |
| 20 kΩ | 0.1 LSB | 0.3 LSB | 1.3 LSB | 8.1 µVrms |

**R = 10 kΩ / 2R = 20 kΩ.** Sub-LSB impedance error with realistic buffers,
noise still negligible, and settling stays fast enough at 1.55 MS/s.

### Resistor tolerance

| Tolerance | Worst-case INL | Effective bits |
|---|---|---|
| 1 % | ±1 % FS = 10 LSB | ~7 |
| **0.1 %** | ±0.1 % FS = 1 LSB | ~10 |

0.1 % is required. Use a **thin-film network array** rather than 20 discretes —
better matching and tracking, fewer placements, lower cost. Prototype with
discretes.

### Why 10 bits

WWVB's −17 dB level is 14.13 % FS and DCF77's is 15 % FS. At 10-bit the LSB is
0.098 % FS, so the low level resolves to 0.65 % relative — comfortably inside
S-03/S-04. 8-bit would give 2.8 % relative: marginal. 12-bit buys nothing here
and costs two GPIO.

**Phase resolution lives in the NCO, not the DAC.** A 10-bit phase LUT
represents 15.6° to within 0.13°, well inside S-07.

---

## 6. Analog chain

### Reconstruction filter

3rd-order Butterworth, f_co = 2 × f_c (Sallen-Key 2nd order + passive RC):

| Variant | f_co | Image freq | Image rejection | Droop at f_c |
|---|---|---|---|---|
| DCF77 | 155 kHz | 1472.5 kHz | ~59 dB | 0.07 dB |
| WWVB/MSF | 120 kHz | 1140 kHz | ~59 dB | 0.07 dB |
| JJY40 | 80 kHz | 760 kHz | ~59 dB | 0.07 dB |

Meets S-13 with margin. For DCF77, C = 1 nF → R ≈ 1.02 kΩ. The filter's phase
shift at f_c (~80°) is **constant** and therefore harmless — it delays the whole
signal equally and does not distort the PM.

### Driver — much smaller than expected

Series-resonant, Q = 25, L = 1 mH at 77.5 kHz → R_total = 19.5 Ω:

| Coil current | Drive voltage | Power | Voltage across L |
|---|---|---|---|
| 10 mA pk | 0.19 V pk | 1.0 mW | 4.9 V pk |
| 30 mA pk | 0.58 V pk | 8.8 mW | 14.6 V pk |
| 50 mA pk | 0.97 V pk | 24.3 mW | 24.3 V pk |

**No power amplifier is needed.** At the 10 mA operating point (≈65 dB under
FCC, §3 of requirements) the driver delivers 1 mW into 19.5 Ω. Slew rate needed
is only 0.49 V/µs. Almost any decent op-amp with ≥50 mA output capability works;
select for low distortion rather than power.

⚠️ **Watch the voltage across the inductor: it is Q× the drive.** At 50 mA that
is 24 V peak across L and the tank capacitor, on a 5 V system. Hence the ≥50 V
C0G rating. This is the classic resonant-circuit trap.

### Output level

Coarse gain is a per-build resistor; fine trim is ≥6 dB in software (R-04).
Do *not* implement the full adjustment range in software — scaling the DAC
codes costs resolution directly.

### Current sense

Small series resistor into ADC0. Enables amplitude self-check (M-06),
production test (M-05), and detecting a disconnected or shorted antenna.

---

## 7. Tank and antenna

Per-variant, Q ≈ 25, L = 1 mH:

| Variant | f_0 | X_L | C (C0G) | R_total | BW | Ring-down τ |
|---|---|---|---|---|---|---|
| DCF77 | 77.5 kHz | 486.9 Ω | 4.217 nF | 19.5 Ω | 3100 Hz | 103 µs |
| WWVB/MSF | 60 kHz | 377.0 Ω | 7.036 nF | 15.1 Ω | 2400 Hz | 133 µs |
| BPC | 68.5 kHz | 430.4 Ω | 5.398 nF | 17.2 Ω | 2740 Hz | 116 µs |
| JJY40 | 40 kHz | 251.3 Ω | 15.831 nF | 10.1 Ω | 1600 Hz | 199 µs |

Q ≈ 25 satisfies DCF77's ~3 kHz PM bandwidth need *and* tolerates ±3 % component
spread without per-unit tuning (M-01, M-02). Ring-down is ≤200 µs — negligible
against a 100 ms AM step.

**Ship the antenna as a matched L+C assembly** (M-03). Coil inductance varies
with winding and ferrite grade; pairing the capacitor to the measured coil at
the supplier removes the one build variable that would otherwise need customer
test equipment.

Form factor: external ferrite rod on a short lead, so the user can lay it
parallel to the watch (E-06 — coupling is strongly orientation-dependent).

---

## 8. Power tree

```
USB-C 5V ─ ESD ─ ferrite ─┬─ LDO1 3.3V ─── RP2350 IOVDD, GNSS, RTC, flash
                          │
                          └─ LDO2 3.0V ─┬─ 74LVC244 buffers  ← DAC REFERENCE
                             low-noise    └─ op-amp
```

**LDO2 is the amplitude reference and needs W-06 treatment** (≤100 µVrms,
10 Hz–1 MHz): low-noise part, generous output capacitance, separate from all
digital loads. Any noise here appears directly as AM on the carrier.

Budget: RP2350 ~100 mW, GNSS ~90 mW tracking (far less duty-cycled), analog
~50 mW, RF ~1–25 mW. Comfortably inside W-02's 1.5 W.

GNSS duty-cycling (default hourly re-acquisition) serves both W-03 and the P-05
holdover mitigation.

---

## 9. PCB

**4-layer, 1.6 mm:** Signal+GND / **solid GND** / 3V3+3V0 planes / Signal.
A continuous reference plane under the analog chain is worth more than the
2-layer cost saving on a mixed-signal board.

### Floorplan

```
 ┌──────────────────────────────────────────────┐
 │ USB-C   power   │ RP2350 + flash │ GNSS  u.FL│
 │  ESD    LDOs    │  TCXO   SWD    │ module    │
 │─────────────────┼────────────────┼───────────│
 │ RTC + CR2032    │ buffers │ R-2R │ LPF       │
 │                 │         │      │ op-amp    │
 │ LED  button     │         │      │ ant conn ─┼──► ferrite rod
 └──────────────────────────────────────────────┘
```

Signal flows left→right, digital→analog, with the antenna connector at the far
edge from USB and the switching supplies.

### Critical layout rules

1. **TCXO adjacent to XIN**, short trace, guarded by ground. Keep the ladder and
   the driver away from it.
2. **R-2R ladder compact and symmetric.** Trace resistance adds directly to the
   ladder — keep branch lengths matched. Ground-flood around it.
3. **Star-ground the analog section** to the main plane at a single point near
   the analog LDO. Do not let return current from the 10 switching DAC lines
   share a path with the driver's return.
4. **Keep the 10 DAC lines short and equal-length**, ≤25 mm, with ground between
   them and the analog nodes.
5. **Antenna leads twisted/differential**, connector away from GNSS. The tank
   carries up to 24 V peak (§6) — respect clearance.
6. **GNSS u.FL and module away from the tank and the DAC.** A 77.5 kHz near
   field is not a direct threat to 1.5 GHz, but the module's own supply and
   harmonics are.
7. Decouple every rail at every pin; 100 nF + bulk per device.

---

## 10. Test and bring-up

**Test points (I-09):** sample clock, DAC out, LPF out, driver out, coil
current, PPS in, PPS out.

**Bring-up order** — each step independently verifiable:

| # | Step | Pass criterion |
|---|---|---|
| 1 | Power, USB enumeration, SWD | Rails within tolerance |
| 2 | TCXO → PLL lock at target sysclk | Measured sysclk correct |
| 3 | PIO sample clock | F_s within 1 ppm of table |
| 4 | DAC ramp → check monotonic | No missing codes, INL ≤1 LSB |
| 5 | Sine at f_c → spectrum | Images ≥55 dB down (S-13) |
| 6 | Filter + driver | THD, level, no clipping |
| 7 | Tank resonance sweep | f_0 within ±1 % (M-05) |
| 8 | AM only, hardcoded time | Reference receiver decodes |
| 9 | PM enabled | Correlation receiver decodes |
| 10 | GNSS + PPS discipline | Epoch error ≤10 ms (P-01) |
| 11 | Real watch | Syncs (F-02) |

**Primary instrument: a 192 kHz USB audio interface.** Nyquist is 96 kHz, so
77.5, 68.5, 60 and 40 kHz all land directly in the audio band — capture with a
pickup coil and analyse in software. No SDR or upconverter. This covers steps
5–9 and the production resonance check.

---

## 11. Cost estimate (indicative, 100 units) 🔶

| Item | Est. |
|---|---|
| RP2350A + flash | €2.50 |
| TCXO 0.5 ppm | €3.00 |
| GNSS module | €8.00 |
| GNSS active antenna | €4.00 |
| DS3231 + CR2032 + holder | €2.50 |
| Buffers, ladder network, op-amp | €2.00 |
| LDOs, passives, ESD | €2.50 |
| Connectors (USB-C, u.FL, headers) | €2.00 |
| Ferrite rod antenna assembly | €3.00 |
| PCB 4-layer | €2.00 |
| Enclosure | €5.00 |
| **Total BOM** | **~€36** |

GNSS + antenna is a third of the cost. If indoor fix reliability proves
acceptable on a cheaper module, or if a USB-time-source SKU (F-13) is offered,
there is meaningful room to cost-reduce.

---

## 12. Next steps

1. Resolve open items 1 (PTB PM spec) and 5 (XIN drive) — both block design freeze.
2. Breadboard **P0**: RP2350 dev board, square wave, hardcoded DCF77 AM, coil.
   Confirms F-02 before any PCB is ordered.
3. Prototype the analog chain on the same dev board (buffers, ladder, filter,
   driver, tank) and run bring-up steps 4–9.
4. Compliance pre-scan of the prototype before layout freeze.
5. Schematic capture → review → PCB rev A.

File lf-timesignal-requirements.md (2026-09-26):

# LF Time-Signal Generator — Design Requirements

Document status: **draft for review**. Requirement IDs are stable; values marked
🔶 are provisional and need confirmation against the cited primary spec or a
compliance authority before design freeze.

Companion documents:
- `lf-timesignal-architecture.md` — system architecture and rationale
- `lf-timesignal-hardware.md` — schematic/PCB design

---

## 0. Product definition

A mains- or USB-powered near-field transmitter that emits **one** LF time-code
signal so that consumer radio-controlled watches and clocks can synchronise
indoors, where the real broadcast is unusable.

**Primary variant: DCF77.** Others are per-build variants of the same PCB.

Two tiers, determined by whether the standard carries phase modulation:

| Tier | Variants | Signal chain |
|---|---|---|
| **Full** | DCF77, WWVB | NCO → DAC → LPF → linear driver → tank |
| **Simple** | MSF, JJY40, JJY60, BPC | PIO square wave → keyed drive → tank |

---

## 1. Functional requirements

| ID | Requirement | Verification |
|---|---|---|
| F-01 | Transmit a complete, standard-conformant time code for the variant's standard, continuously, one frame per minute. | Decode with reference receiver |
| F-02 | Synchronise at least one real production radio-controlled watch to the correct time and date. | Physical test, ≥3 watch models |
| F-03 | Derive UTC from GNSS without any network connection. | Functional test, airgapped |
| F-04 | Derive the correct broadcast-local time (incl. DST) algorithmically, with no tzdata and no network. | Unit test sweep, §5 |
| F-05 | Maintain correct output through a total loss of GNSS for the holdover period (P-05). | Bench test with antenna disconnected |
| F-06 | Retain time across a power cycle via battery-backed RTC. | Power-cycle test |
| F-07 | Emit DCF77 phase modulation (Full/DCF77 variant). | PM correlation decode |
| F-08 | Emit WWVB BPSK (Full/WWVB variant). | BPSK decode |
| F-09 | Provide a user-initiated "transmit now" action. | Functional |
| F-10 | Support a scheduled transmit window (default: enabled, 01:00–05:00 local). | Functional |
| F-11 | Refuse to transmit if the firmware variant and hardware strap disagree; indicate the fault. | Fault-injection test |
| F-12 | Expose a USB serial console for configuration, status and diagnostics. | Functional |
| F-13 | Accept an external UTC source over USB as a GNSS fallback. | Functional |
| F-14 | Indicate operating state (no time / holdover / locked / transmitting / fault) on an indicator. | Visual inspection |

### Explicit non-goals

| ID | Non-goal |
|---|---|
| NG-01 | Runtime switching between standards. Fixed per build. |
| NG-02 | Useful range beyond ~0.5 m. Range is deliberately bounded (see R-03). |
| NG-03 | Network/Wi-Fi connectivity. |
| NG-04 | Battery operation. USB-powered. |
| NG-05 | Substituting for a traceable laboratory time standard. |

---

## 2. Performance requirements

### Timing

| ID | Requirement | Value | Notes |
|---|---|---|---|
| P-01 | Second-marker error vs UTC, GNSS locked | **≤ 10 ms** | Dominated by firmware scheduling, not GNSS |
| P-02 | Second-marker error, ≤24 h since last fix | ≤ 50 ms | |
| P-03 | Internal epoch resolution | 1 sample (≤ 0.65 µs) | Sample-counted scheduler |
| P-04 | GNSS PPS capture jitter | ≤ 1 µs | |
| P-05 | **Holdover: error after 7 days with no GNSS** | **≤ 500 ms** | Requires ≤ 0.83 ppm — see note |
| P-06 | Time-to-first-transmit from cold start with GNSS | ≤ 5 min | |
| P-07 | Time-to-first-transmit from RTC only | ≤ 5 s | Degraded-accuracy mode |

> **Holdover drives the reference choice.** 7 days at ±500 ms permits only
> 0.83 ppm. A 0.5 ppm TCXO gives ~300 ms over 7 days (pass); a 2 ppm part gives
> ~1.2 s (fail). Note this is *residual* stability after GNSS has taught the
> firmware the part's offset — absolute initial accuracy is irrelevant.
> **Mitigation:** duty-cycled GNSS re-acquisition (default hourly) keeps normal
> operation far inside P-02, so P-05 only applies to a genuinely blind unit.

### Signal quality

| ID | Requirement | Value | Notes |
|---|---|---|---|
| S-01 | Carrier frequency error | ≤ ±10 ppm | Receiver front-ends are far looser; easily met |
| S-02 | Carrier frequency, coherence | f_c = F_s / 20 exactly | Structural, not a tolerance |
| S-03 | AM low-level accuracy (DCF77 15%) | ±1.5% absolute 🔶 | Confirm against PTB |
| S-04 | AM low-level accuracy (WWVB −17 dB) | ±1 dB | |
| S-05 | AM transition ramp time | 0.5–2 ms, monotonic 🔶 | Limits splatter; confirm shape vs PTB |
| S-06 | AM timing accuracy (drop start/length) | ≤ ±1 ms | |
| S-07 | PM phase deviation (DCF77) | ±15.6° ± 0.5° | |
| S-08 | PM chip rate | f_c/120 = 645.833 Hz exactly | Structural: 2400 samples/chip |
| S-09 | PM sequence | 512 chips, start +200 ms, end +992.77 ms | Verified consistent; obtain PRBS polynomial from PTB |
| S-10 | PM suppressed during AM drop | Yes | Guaranteed by the +200 ms start |
| S-11 | BPSK phase offset vs AM step (WWVB) | +100 ms ± 1 ms | Deliberate in the NIST spec |
| S-12 | Spurious/harmonic at antenna | ≤ −50 dBc 🔶 | Set by DAC + LPF + tank |
| S-13 | Sampling image rejection | ≥ 55 dB | 3rd-order LPF at 2×f_c gives ~59 dB |
| S-14 | Amplitude stability over temperature | ≤ ±5% over 0–40 °C | |

### Field strength and range

| ID | Requirement | Value | Notes |
|---|---|---|---|
| R-01 | Reliable watch sync distance | ≥ 5 cm, aligned | With ferrite-rod antenna |
| R-02 | Typical usable distance | 10–30 cm | |
| R-03 | **Design-bounded maximum** | ≤ 1 m | Deliberate: compliance and interference safety |
| R-04 | Output level adjustable | ≥ 6 dB software trim | Plus per-build analog gain resistor |

---

## 3. Regulatory requirements

> ⚠️ **These are design targets, not a compliance assessment.** The values below
> are engineering estimates for internal use. Formal applicability, measurement
> distance, extrapolation factors and test method **must** be confirmed with a
> qualified compliance body before sale. Selling a kit does not reliably reduce
> obligation.

| ID | Requirement | Notes |
|---|---|---|
| G-01 | Design margin ≥ 20 dB below the applicable radiated-emission limit | Calculated margin is ~65–70 dB at 10 mA drive |
| G-02 | Comply with FCC 47 CFR §15.209 (WWVB variant, US) 🔶 | Limit ≈ 31 µV/m at 300 m at 77.5 kHz |
| G-03 | Comply with EN 300 330 + EMC/LVD for CE/UKCA (DCF77, MSF variants) 🔶 | |
| G-04 | Japan MIC conformity (JJY variants) 🔶 | Known to be strict; treat as a separate business decision |
| G-05 | Conducted USB emissions within limits | |
| G-06 | RoHS/REACH compliant BOM | |
| G-07 | Not marketed or capable of interfering beyond the premises | Supported by R-03 |

**Estimated margin** (100-turn, 5 cm radius loop, 10 mA peak):

| Distance | Field | Reference |
|---|---|---|
| 10 cm | 119 dBµA/m | operating point |
| 10 m | 1.9 dBµA/m | vs EN-style 72 dBµA/m → **~70 dB margin** |
| 300 m | 0.017 µV/m equiv | vs FCC 31 µV/m → **~65 dB margin** |

Near-field 1/r³ rolloff dominates. Using E = 377·H is **conservative** here: a
magnetic dipole's near-field wave impedance is below 377 Ω, so true E is lower
than the figures above.

---

## 4. Interface requirements

| ID | Requirement |
|---|---|
| I-01 | USB-C receptacle, USB 2.0 full-speed, 5 V input, ≤ 500 mA |
| I-02 | USB CDC serial console, 115200 8N1, line-based text protocol |
| I-03 | USB Mass Storage bootloader (BOOTSEL) for firmware update — no programmer needed |
| I-04 | SWD header (2.54 mm or Tag-Connect) for development |
| I-05 | GNSS active antenna via u.FL or SMA, with switchable antenna bias |
| I-06 | Antenna coil on a 2-pin polarised connector, keyed, per-variant matched assembly |
| I-07 | CR2032 holder for RTC backup |
| I-08 | Variant strap: 3 GPIO, resistor-configured, 8 possible variants |
| I-09 | Test points: sample clock, DAC out, LPF out, driver out, coil current, PPS in, PPS out |

---

## 5. Time and DST rule requirements

| ID | Requirement |
|---|---|
| T-01 | DST/offset rules stored as **parameters in flash**, not hardcoded |
| T-02 | DCF77: CET/CEST, EU rule (last Sun Mar / last Sun Oct, 01:00 UTC) |
| T-03 | MSF: UTC/BST, same instants as the EU rule |
| T-04 | WWVB: UTC + DST status bits, US rule (2nd Sun Mar / 1st Sun Nov) |
| T-05 | JJY: JST = UTC+9, no DST, ever |
| T-06 | BPC: UTC+8, no DST, ever |
| T-07 | DCF77 A1 (bit 16) set during the hour preceding a DST change |
| T-08 | DCF77 A2 (bit 19) set for an announced leap second |
| T-09 | Leap-second state taken from the GNSS navigation message (current + pending) |
| T-10 | Correct behaviour across a leap-second insertion |
| T-11 | Unit tests sweep ≥20 years of transitions, both directions, both hemispheres of the rule |
| T-12 | Frame encodes the **upcoming** minute, transmitted from second 0 |

---

## 6. Environmental and mechanical

| ID | Requirement | Value |
|---|---|---|
| E-01 | Operating temperature | 0 to +40 °C |
| E-02 | Storage temperature | −20 to +60 °C |
| E-03 | Humidity | 10–90% RH non-condensing |
| E-04 | Enclosure | Desktop, non-conductive (plastic) — must not shield the coil |
| E-05 | Max dimensions (main PCB) | 80 × 60 mm |
| E-06 | Antenna | External ferrite rod on short lead, user-orientable |
| E-07 | ESD | ±4 kV contact on exposed connectors 🔶 |

> **E-04 and E-06 are coupled and easy to get wrong.** A watch's receiver uses a
> ferrite rod antenna; coupling is strongly orientation-dependent. A flat coil
> under a watch laid on top produces a field largely orthogonal to the watch's
> rod — poor coupling. A ferrite rod the user can lay *parallel* to the watch is
> markedly better and is the recommended form factor.

---

## 7. Power

| ID | Requirement | Value |
|---|---|---|
| W-01 | Input | 5 V ±5% from USB-C |
| W-02 | Total power, transmitting | ≤ 1.5 W |
| W-03 | Total power, idle (outside transmit window) | ≤ 0.5 W |
| W-04 | RF power into antenna | ~1–25 mW (see R-04) |
| W-05 | RTC backup current | ≤ 3 µA (≥ 5 years on CR2032) |
| W-06 | Analog supply noise at DAC reference | ≤ 100 µVrms, 10 Hz–1 MHz |
| W-07 | Inrush compliant with USB spec | |

---

## 8. Manufacturing and kit requirements

| ID | Requirement |
|---|---|
| M-01 | No per-unit tuning or calibration requiring test equipment |
| M-02 | Tank tolerates ±3% L and C spread without retuning (satisfied at Q ≈ 25) |
| M-03 | Antenna supplied as a pre-wound, pre-matched assembly with its capacitor |
| M-04 | Fine-pitch/QFN parts factory-assembled; kit content limited to through-hole and connectors |
| M-05 | Production test: verify resonance within ±1% of target, verify AM depth, verify a decoded frame |
| M-06 | Firmware self-test at boot: strap match, RTC present, GNSS comms, DAC continuity |
| M-07 | Per-variant differences limited to: PLL constants, tank capacitor, filter RC, gain resistor, build flag, silkscreen |

---

## 9. Software requirements (summary)

| ID | Requirement |
|---|---|
| SW-01 | Three-layer separation: timebase / standard / modulator (see architecture §4) |
| SW-02 | Frame encoders are pure functions of civil time → bits; no I/O, fully unit-testable on host |
| SW-03 | Golden-vector tests: known timestamp → expected bit pattern, per standard |
| SW-04 | Modulator runs from DMA double-buffering; must never underrun |
| SW-05 | Sample-generation CPU load ≤ 50% of one core, measured |
| SW-06 | Learned TCXO ppm correction persisted to flash, with sanity bounds |
| SW-07 | Fractional samples-per-second accumulator for epoch discipline (see architecture §3a) |
| SW-08 | Watchdog; safe state = transmitter off |
| SW-09 | Firmware update over USB MSC without special tools |

---

## 10. Open items

| # | Item | Blocks | Owner |
|---|---|---|---|
| 1 | Obtain PTB DCF77 PM specification: PRBS polynomial, seed, exact chip alignment | F-07, S-09 | — |
| 2 | Confirm DCF77 AM envelope shape/ramp spec | S-05 | — |
| 3 | Compliance pre-assessment for the launch variant and region | G-01…G-04 | — |
| 4 | Select GNSS module; confirm PPS spec and duty-cycle behaviour | P-04, P-05 | — |
| 5 | Confirm RP2350 XIN external-clock drive levels for TCXO | hardware | — |
| 6 | Decide launch region and therefore launch variant | all | — |
| 7 | Measure real watch sensitivity to set R-01 drive level empirically | R-01, R-04 | — |

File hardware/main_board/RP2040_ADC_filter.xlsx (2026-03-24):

https://www.analog.com/en/resources/analog-dialogue/articles/front-end-amp-and-rc-filter-design.html
maximum step size: | 5.183627878 | Vstep: | 0.0112443121 | Ntc: | 3.32909801 | Vhalf_lsb: | 0.0004028320312 | tACQ: | 2e-06 | RC time constant | 6.007633282e-07
fin: | 250000 | Cadc: | 5e-12 |  |  | Vref: | 3.3 | TSR | 4e-06
Vpeak: | 1.65 | Cext: | 2.3e-09 |  |  | ADC bits | 12 | tconv | 2e-06
tconv: | 2e-06
 |  |  |  |  |  |  |  |  |  | Rext: | 261.201447
ADC resolution | 12
Adc clock (MHz) | 48000000
total ADC clock cycles | 96
total ADC time | 2e-06
ADC conversion time (approx) | 2.5e-07
ADC acquisition time (approx) | 1.75e-06
ADC Csh | 1e-12
ADC C parasitic | 4e-12
Rsh | 100000
Rsh (approx ???) | 17500
ADC acquisition time (approx ???) | 5e-05

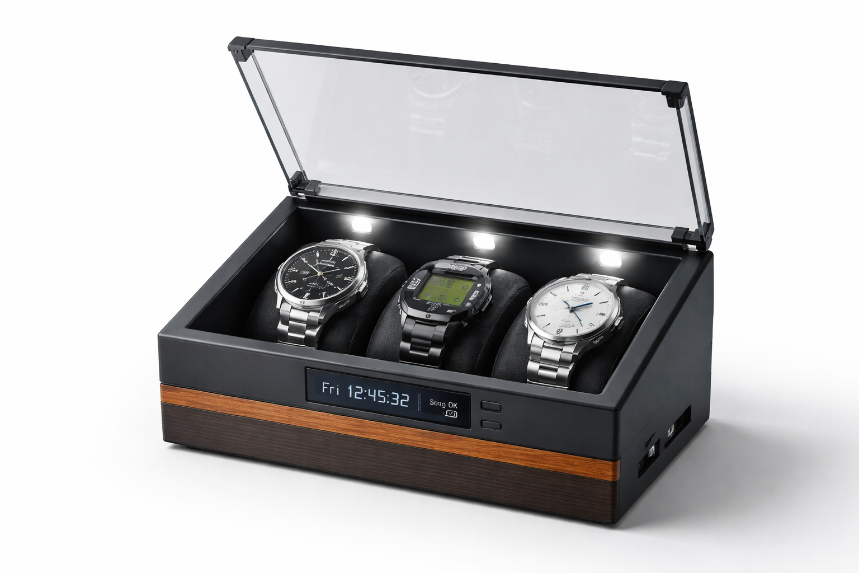
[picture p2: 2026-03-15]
images/Concept Render.png

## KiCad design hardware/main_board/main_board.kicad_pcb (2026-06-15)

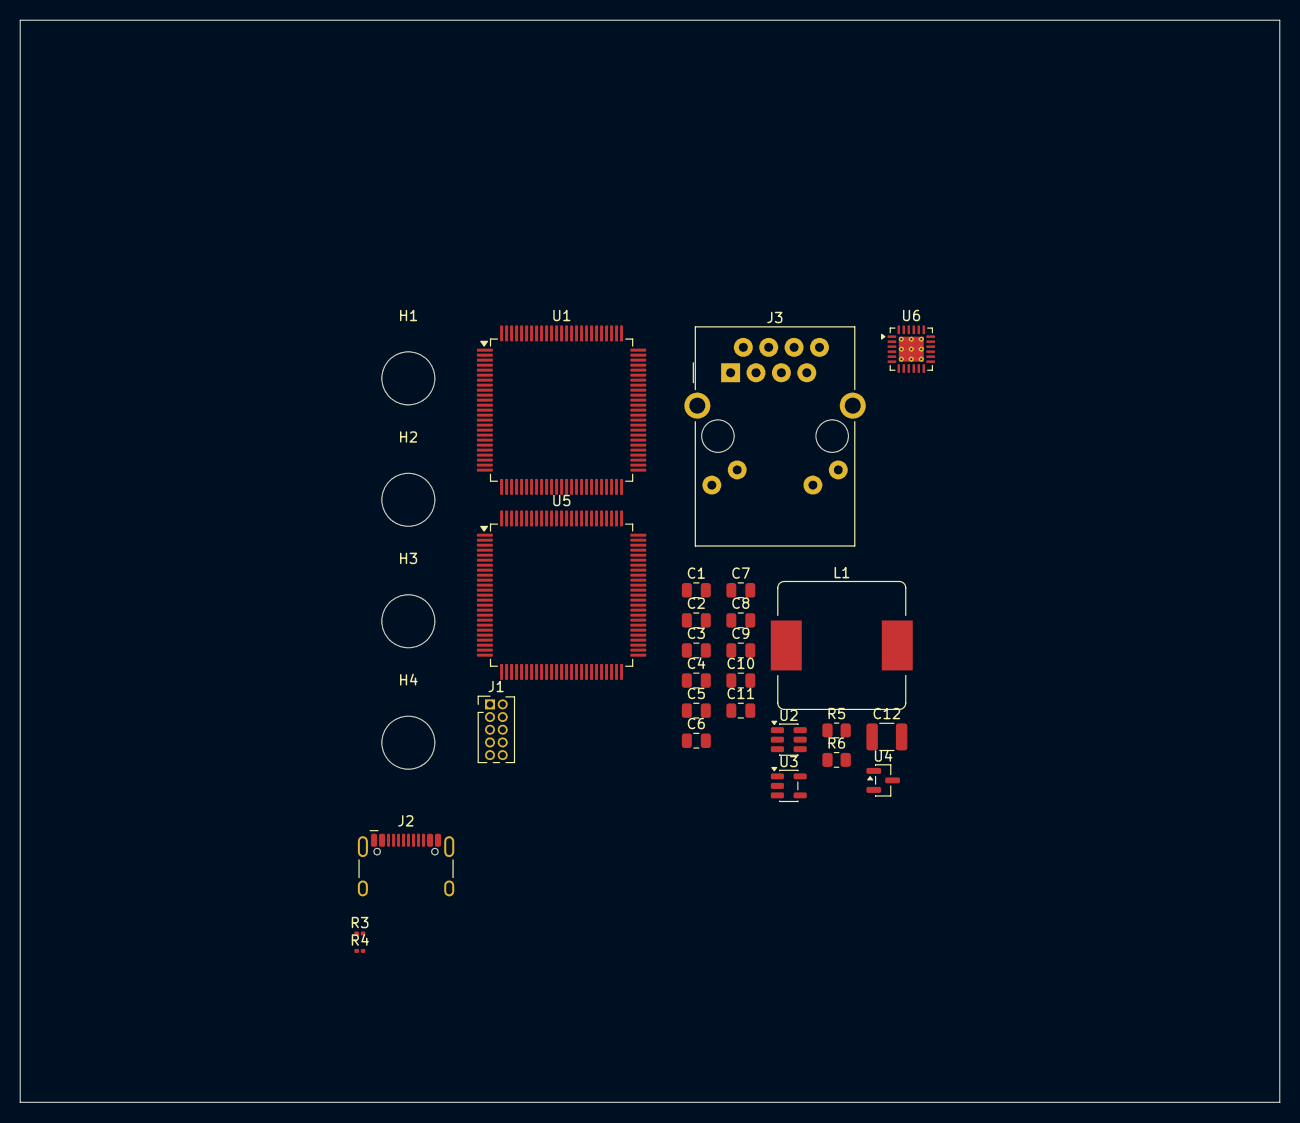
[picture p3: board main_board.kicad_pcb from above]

Board: 4 copper layers, 126.0 x 108.2 mm, 30 parts (0 on the bottom side), 11 nets, no tracks yet.

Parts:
C1, C3, C4, C8, C9: 100nC; C_0805_2012Metric
C2, C5, C6, C7, C10: 10uC; C_0805_2012Metric
C11: C; C_0805_2012Metric
C12: C; C_1210_3225Metric
H1, H2, H3, H4: MountingHole; MountingHole_5.3mm_M5
J1: Conn_ARM_JTAG_SWD_10; PinHeader_2x05_P1.27mm_Vertical
J2: USB_C_Receptacle_USB2.0_16P; USB_C_Receptacle_HCTL_HC-TYPE-C-16P-01A
J3: RJ45_Amphenol_RJMG1BD3B8K1ANR
L1: L; L_TaiTech_TMPC1265_13.5x12.5mm
R3, R4: 27R; R_0201_0603Metric
R5, R6: R; R_0805_2012Metric
U1: STM32H563VITx; LQFP-100_14x14mm_P0.5mm
U2: TPS54202DDC; SOT-23-6
U3: TLV75533PDBV; SOT-23-5
U4: REF3033; SOT-23
U5: STM32F407VETx; LQFP-100_14x14mm_P0.5mm
U6: LAN8742A; VQFN-24-1EP_4x4mm_P0.5mm_EP2.5x2.5mm_ThermalVias

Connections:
+3.3V: C8.1, C10.1, J1.1 (VTref), U3.5 (OUT)
+12V: C1.1, C2.1, C5.1, U2.3 (VIN), U2.5 (EN)
GND: C1.2, C2.2, C3.2, C4.2, C5.2, C6.2, C7.2, C8.2, C10.2, C12.2, J1.3 (GND), J1.5 (GND), J1.9 (GNDDetect), J2.A1 (GND), J2.A12 (GND), J2.B1 (GND), J2.B12 (GND), J2.SH (SHIELD), R6.2, U2.1 (GND), U3.2 (GND), U4.3 (GND)
unnamed: J2.A6 (D+), J2.B6 (D+), R4.1
unnamed: J2.A7 (D-), J2.B7 (D-), R3.1
unnamed: U1.10 (VSS), U1.27 (VSS), U1.49 (VSS), U1.74 (VSS), U1.99 (VSS)
unnamed: C9.1, U2.6 (BOOT)
unnamed: C11.2, R5.2, R6.1, U2.4 (FB)
unnamed: C9.2, L1.1, U2.2 (SW)
unnamed: C3.1, C4.1, C6.1, C7.1, C11.1, C12.1, L1.2, R5.1, U3.1 (IN), U3.3 (EN), U4.1 (IN)
unnamed: U5.10 (VSS), U5.27 (VSS), U5.74 (VSS), U5.99 (VSS)

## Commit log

2026-03-15 Updates README with project details
    Expanded the README to provide detailed information about TimeNest, including features, system architecture, hardware components, antenna design, enclosure specifications, repository structure, roadm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
2026-03-24 Created new PCB project.
    [RP2040_ADC_filter.xlsx, main_board.kicad_pcb, main_board.kicad_sch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]
2026-06-15 Progressed ECAD.
    [USB.kicad_sch, ethernet.kicad_sch, main_board.kicad_pcb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]
2026-09-26 Add LF time-signal design docs
    Add the LF time-signal generator requirements, architecture, and hardware design documents. The change formalizes the variant requirements, timing/PM constraints, analog tank and driver sizing, RP235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
